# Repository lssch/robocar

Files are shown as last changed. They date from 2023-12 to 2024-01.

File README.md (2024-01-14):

# robocar
This is a third semester project at FHGR to develop a semi autonomous rc car with simple obstacle avoidance. The project consists of three main software components:

- [**STM32 Firmware**](https://github.com/lssch/STM32_Robocar_FW)
- [**ESP32 Firmware**](https://github.com/lssch/ESP32_Robocar_FW)
- [**GUI**](https://github.com/lssch/GUI_robocar)

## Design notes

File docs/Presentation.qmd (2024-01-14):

---
title: "Robocar"
subtitle: "Mobiles Robotikprojekt I"
author: "Lars Schwarz"
date: last-modified
lang: de

title-block-banner: blue
format:
  revealjs: 
    scrollable: true
    multiplex: true
    transition: slide
    transition-speed: fast
    html-math-method: mathjax
    slide-number: true
    show-slide-number: all
    progress: false
    history: true
    chalkboard: true
    preview-links: auto
---

# Übersicht
:::: {.columns}

::: {.column}
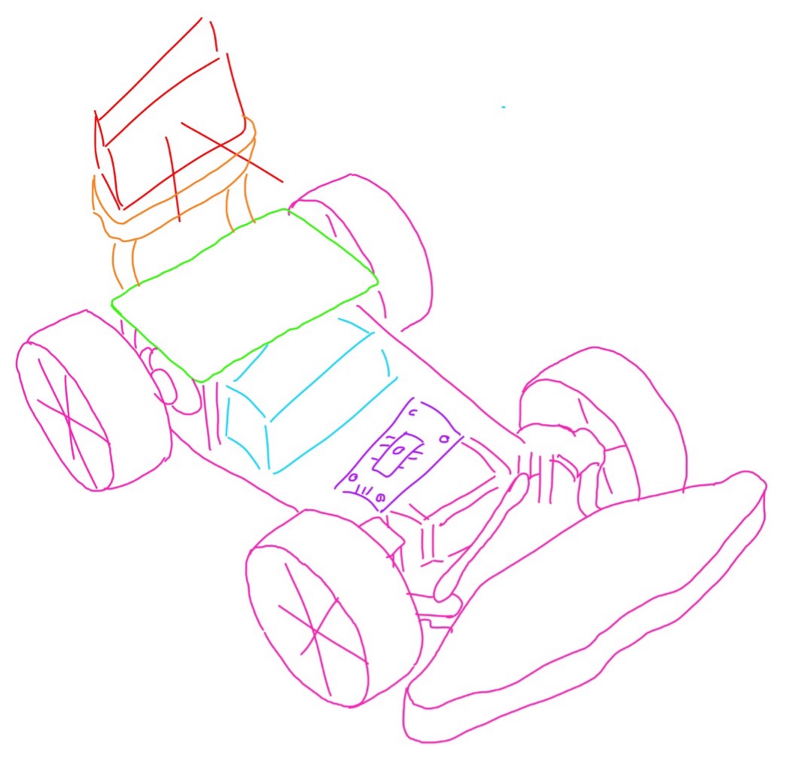
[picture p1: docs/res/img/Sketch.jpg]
Sketch

:::
::: {.column}
::: {.incremental}
- Ferngesteuertes RC-Auto
- Teil-/Vollautonom 
:::
:::

::::

# Mechanik
:::: {.columns}

::: {.column}
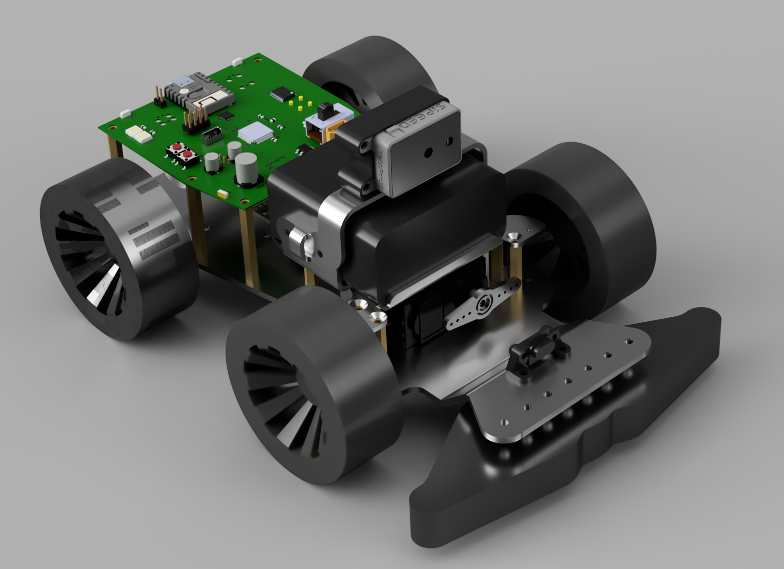
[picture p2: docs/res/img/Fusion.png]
Fusion-Export

:::

::: {.column}
::: {.incremental}
- Neue Grundplatte
- Batteriehalter
- ToF-Kamerahalter
- ToF-Spot-Halter
- Beleuchtungsring VFS
:::
:::
::::

# Elektronik
:::: {.columns}

::: {.column}
::: {.panel-tabset group="language"}

## Vorderseite
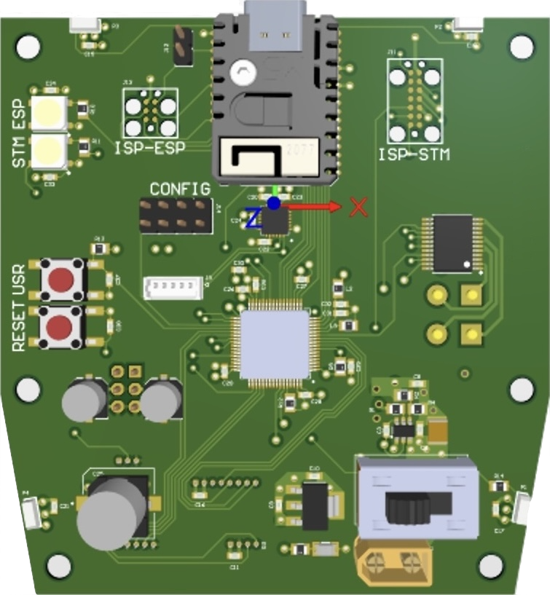
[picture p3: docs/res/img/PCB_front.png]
Vorderseite


## Rückseite
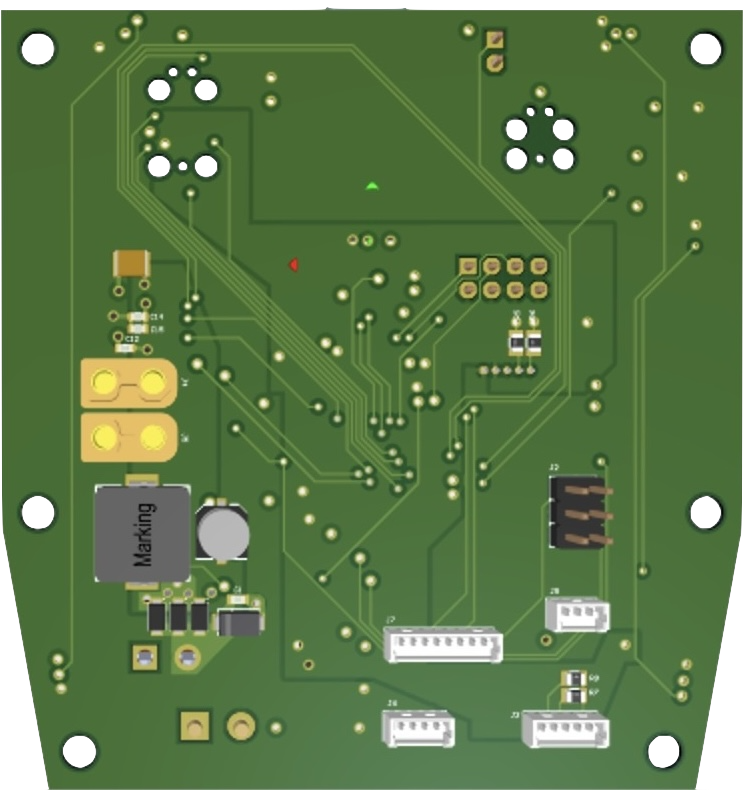
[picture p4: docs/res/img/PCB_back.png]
Rückseite


:::
:::

::: {.column}
::: {.incremental}
- Platzsparend
- Keine Steckmodule
:::

::: {.fragment}
**Fehler**

- RX/TX für debugging vertauscht
:::

::: {.fragment}
**Siliziumhimmel**

- 1 Mikrocontroller
- 4 H-Brücken
:::

:::

::::

# Software
Comments

## Softwareaufbau
::: {.incremental}
- 3 Verschiedene Oberflächen
  - **Firmware**: STM32 in C++
  - **Firmware**: ESP32 in C++
  - **GUI**: Robocar Visualisierung in [Typescript](https://www.typescriptlang.org/)
- Eigene Softwaremodule für jede Hardwarekomponente
  
  :::: {.columns}
  ::: {.column}
    - IMU
    - ToF-Kamera
    - Visual-Flow-Sensor
  :::
  ::: {.column}
    - Neopixel
    - Servo
    - H-Brücke
  :::
  ::::
:::

## Kommunikation mit GUI
```{mermaid}
sequenceDiagram
    participant STM32
    participant ESP32
    participant Laptop

    Note over ESP32,STM32: SPI fullduplex

    loop Sync
      ESP32 -> STM32: package TX/RX
    end

    loop Sample
      ESP32 ->> Laptop: EUI read package
    end

    Laptop ->> ESP32: EUI write package

    Note over ESP32,Laptop: UART
```

## Regelung
$$x_{\text{a}}(t) = K_{\text{p}} \cdot x_{\text{e}}(t) + K_{\text{i}} \cdot \int x_{\text{e}}(t) \, \mathrm{d} t + K_{\text{d}} \cdot \dot x_{\text{e}}(t) $$

::: {.fragment}
:::: {.columns}
::: {.column}
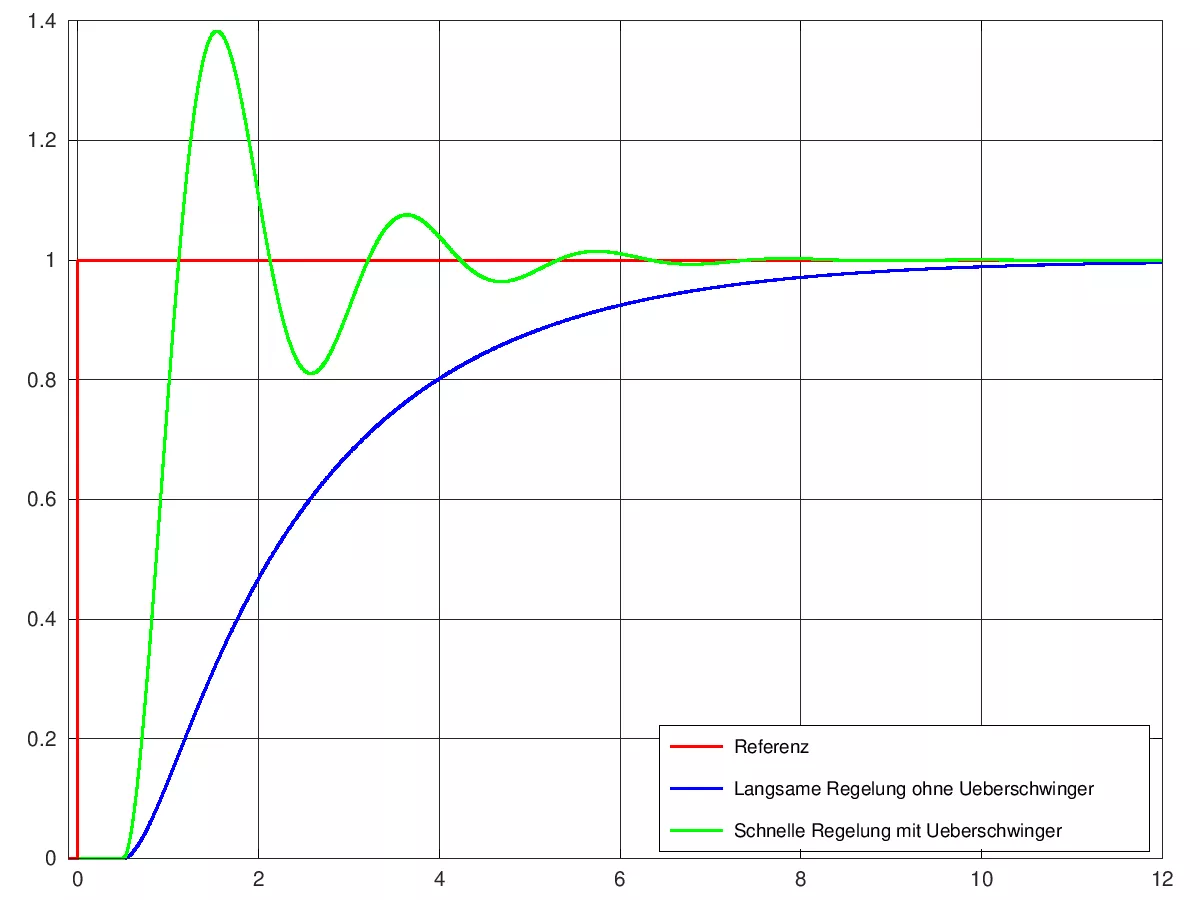
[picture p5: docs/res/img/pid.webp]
Sprungantwort

:::

::: {.column}
::: {.incremental}
- Geschwindigkeit
- Abstand zu Objekt
- Tuning von $K_{\text{p}}, K_{\text{i}}, K_{\text{d}}$
:::
:::
:::
::::

## Falsches Tuning

{{< video res/data/PID.mov >}}

## Codestats {auto-animate=true}
```{mermaid}
%%{init: {"pie": {"textPosition": 0.5}} }%%
   pie
    title Eigene Codezeilen
    "STM32 ca. 2'500" : 2500
    "ESP32 ca. 900" : 900
    "GUI ca. 3'300" : 3300
```

## Codestats {auto-animate=true}
```{mermaid}
%%{init: {"pie": {"textPosition": 0.5}} }%%
pie title Anzahl Codezeilen
    "Eigene STM32 ca. 2'500" : 2500
    "Eigene ESP32 ca. 900" : 900
    "Eigene GUI ca. 3'300" : 3300
    "STM32 ca. 33'500" : 33500
    "ESP32 ca. 16'100" : 16100
    "GUI ca. 236'700" : 236700
```

# Demonstration

# Fragen

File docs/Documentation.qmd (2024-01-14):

---
title: "Dokumentation Robocar"
subtitle: "Mobiles Robotikprojekt I"
author: "Lars Schwarz"
date: last-modified

title-block-banner: blue

toc: true
number-sections: false
highlight-style: pygments

format:
  html:
    code-fold: true
    code-tools:
      source: false
      toggle: true
    code-line-numbers: true
    code-overflow: scroll
    html-math-method: mathjax
  pdf:
    pdf-engine: pdflatex
    latex-auto-install: true
    documentclass: article
    papersize: a4
    geometry:
      - left=2cm
      - right=2cm
      - top=2cm
      - bottom=2cm
    lof: true
    header-includes:
      - \usepackage{bbold}
      - \usepackage{float}
      - \floatplacement{figure}{H}
      - \newcommand{\N}{\mathbb{N}}
      - \newcommand{\Z}{\mathbb{Z}}
      - \newcommand{\Q}{\mathbb{Q}}
      - \newcommand{\R}{\mathbb{R}}
      - \newcommand{\C}{\mathbb{C}}
      - \newcommand{\D}{\mathbb{D}}
      - \newcommand{\W}{\mathbb{W}}
      - \newcommand{\M}{\mathbb{M}}
      - \newcommand{\K}{\mathbb{K}}
      - \newcommand{\e}{\mathrm{e}}
      - \renewcommand{\i}{\mathrm{i}}
      - \renewcommand{\j}{\mathrm{j}}
      - \newcommand{\dd}{\,\mathrm{d}}
      - \newcommand{\pp}{\partial}
      - \newcommand{\NA}{\text{N/A}}
      - \newcommand{\ul}[1]{\underline{#1}}
      - \newcommand{\uul}[1]{\underline{\underline{#1}}}
      - \renewcommand{\vec}[1]{\boldsymbol{\mathrm{#1}}}
      - \newcommand{\uvec}[1]{\boldsymbol{\hat{\mathrm{#1}}}}
      - \newcommand{\abs}[1]{\left\vert#1\right\vert}
      - \newcommand{\vabs}[1]{\left\vert\left\vert#1\right\vert\right\vert}
      - \renewcommand{\angle}[1]{\left\langle#1\right\rangle}
      - \newcommand{\ceil}[1]{\left\lceil#1\right\rceil}
      - \newcommand{\floor}[1]{\left\lfloor#1\right\rfloor}
      - \newcommand{\sgn}[1]{\operatorname{sgn}\left(#1\right)}
      - \renewcommand{\Re}[1]{\operatorname{Re}\left(#1\right)}
      - \renewcommand{\Im}[1]{\operatorname{Im}\left(#1\right)}
      - \newcommand{\cis}[1]{\operatorname{cis}\left(#1\right)}
      - \renewcommand{\arg}[1]{\operatorname{arg}\left(#1\right)}
      - \renewcommand{\div}[1]{\operatorname{div}\left(#1\right)}
      - \newcommand{\rot}[1]{\operatorname{rot}\left(#1\right)}
      - \newcommand{\tr}[1]{\operatorname{tr}\left(#1\right)}
      - \renewcommand{\det}[1]{\operatorname{det}\left(#1\right)}
      - \newcommand{\spec}[1]{\operatorname{Spec}\left(#1\right)}
      - \renewcommand{\dim}[1]{\operatorname{dim}\left(#1\right)}
      - \newcommand{\img}[1]{\operatorname{img}\left(#1\right)}
      - \renewcommand{\ker}[1]{\operatorname{ker}\left(#1\right)}
---

{{< pagebreak >}}

# Einführung
Diese Dokumentation dient zur Bedienung und Weiterentwicklung des "Robocars", das im Rahmen des [Mobile Robotics Projekt 1](https://www.fhgr.ch/fileadmin/studium/bachelorangebot/mobile_robotics/FHGR-Bachelorstudium-Mobile_Robotics-Moduluebersicht.pdf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) an der [FHGR](https://fhgr.ch) während des dritten Semesters entwickelt wurde.

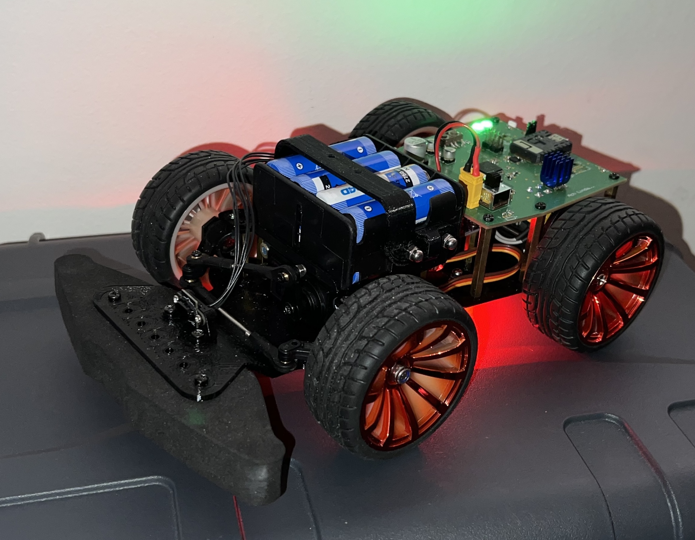
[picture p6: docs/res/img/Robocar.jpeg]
Robocar


Sämtliche Files sind in folgemdem [GitHub-Repo](https://github.com/lssch/robocar) zu finden.

::: {.callout-note title="Info"}
- Diese Dokumentation soll als Zusatz dienen und nicht als Ersatz für die Sourcecode Dokumentation.
- Dieses Dokument wurde mit [Quarto-Markdown](https://quarto.org) erstellt und ist sowohl in PDF (ohne Videos) als auch in HTML (bevorzugt) verfügbar.
:::

# Übersicht
Das Robocar basiert auf einem stark modifiziertem Chassis von [YF-Robot](https://yfrobot.com/collections/robot-kits/products/steering-gear-robot) und verwendet einen [STM-32F446RE](https://www.st.com/en/microcontrollers-microprocessors/stm32f446re.html) Mikrocontroller, welcher auf einem eigens dafür entworfenem PCB mit verschiedenen Peripherien ([M5Stack ESP32-S3](https://docs.m5stack.com/en/core/StampS3), [IMU](https://invensense.tdk.com/products/motion-tracking/6-axis/mpu-6050/), [ToF-Kamera](https://wiki.sipeed.com/hardware/en/maixsense/index.html), [ToF-Sensor](), [Visual-Flow-Kamera](https://www.mouser.ch/ProductDetail/Broadcom-Avago/ADNS-3080?qs=RuhU64sK2%252Bsop/60ZpFX6g%3D%3D)) kommuniziert.

Das Robocar soll mittels sehr günstiger Hardware ferngesteuert werden und als weiterführende Ziele gewisse Assistenzfunktionen wie Kollisionsdetektion und Spurhalteasistenz verfügen. Weiter soll eine einfache Kollisionsverhinderung mittels Ausweichmanöver implementiert sein.

{{< pagebreak >}}

# Handbuch
## Benötigte Komponenten
- Robocar
- Geladene Batterien!
- Laptop mit GUI-Applikation

::: {.callout-tip title="Tip"}
  Sicherstellen, dass die Batterien ganz geladen sind.
:::

## Hardware

1. Geladene Batterien in den Batteriehalter einsetzen.
2. Batteriehalter in die vorgesehene Halterung einsetzen.
3. Batteriestecker XT30 mit dem PCB verbinden.
4. Robocar am Hauptschalter einschalten.

::: {.callout-important title="Vorsicht"}
  <p>
    Beim Einsetzen der Batteriehalterung in die vorgesehene Position auf dem Robocar, muss darauf geachtet werden, dass die Litzen des ToF-Spot Sensors nicht gequetscht werden!
  </p>
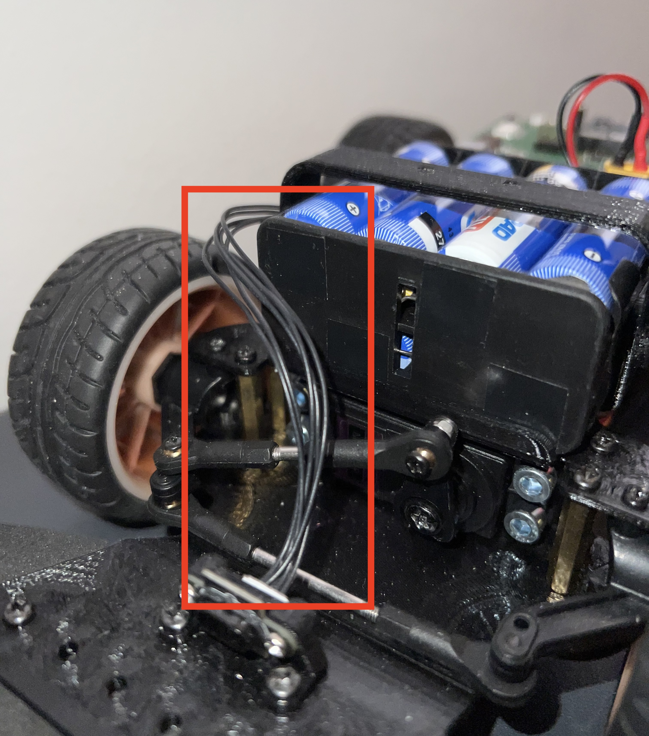
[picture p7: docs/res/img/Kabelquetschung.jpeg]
Kabelquetschung
  
:::

## GUI 
Über die GUI können alle Sensordaten live abgefragt werden und alle Parameter persistent verändert werden.

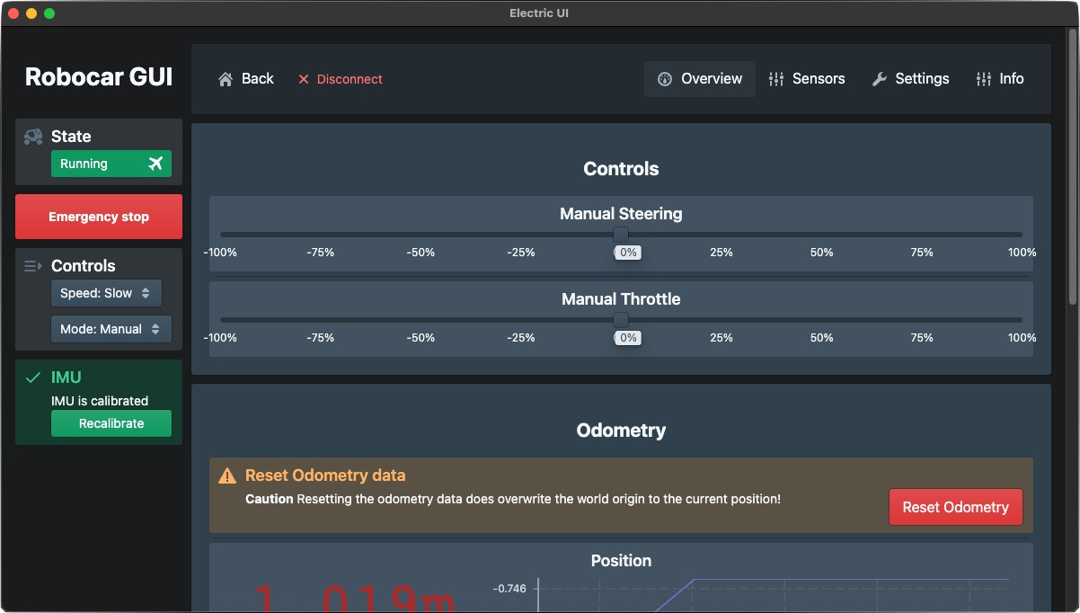
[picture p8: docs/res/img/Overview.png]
GUI Robocar


1. GUI-Applikation starten

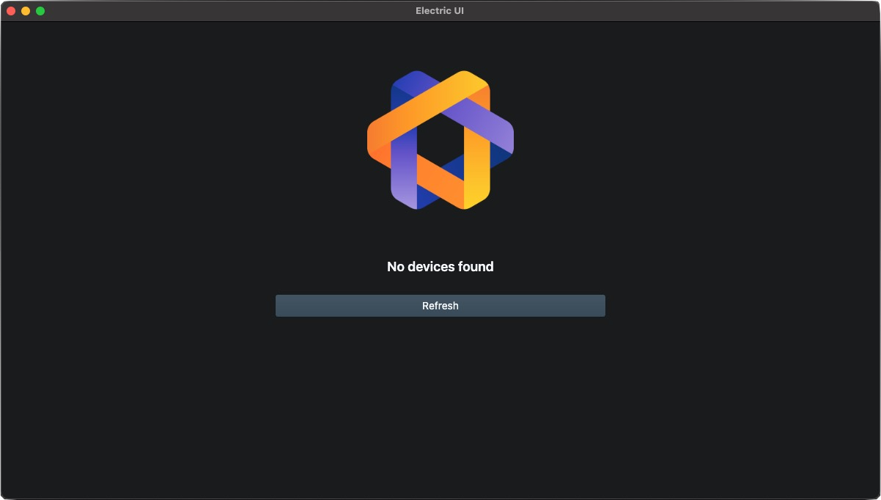
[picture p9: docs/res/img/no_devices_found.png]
GUI Robocar keine Geräte
  

1. Verbindung mit dem Robocar über WIFI/Bluetooth oder Serial (kabelgebunden) herstellen.

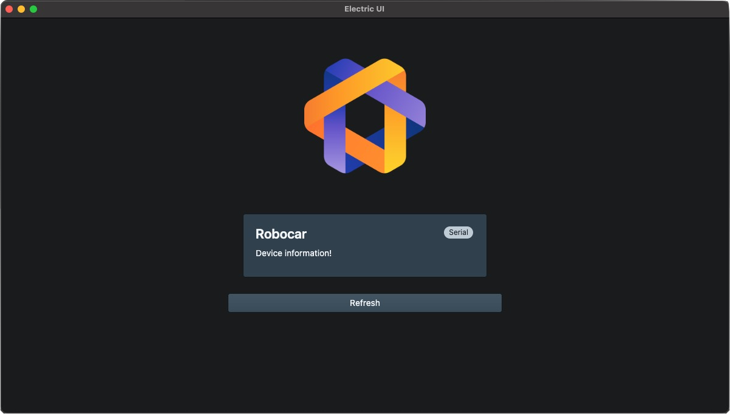
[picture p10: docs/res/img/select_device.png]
GUI Robocar verbinden mit Endgerät
  

1. Werte und Parameter abfragen

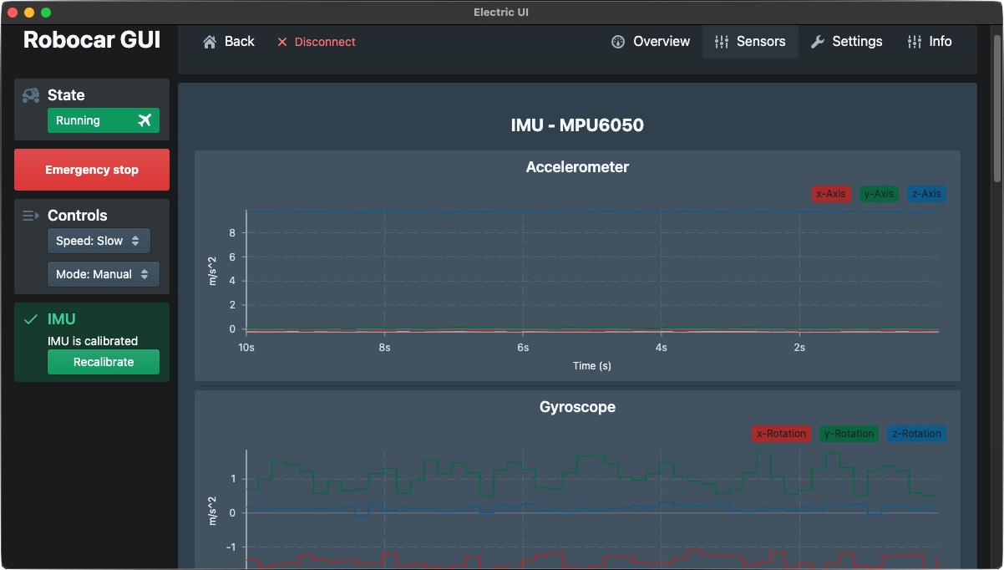
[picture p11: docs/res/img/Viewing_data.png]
GUI Robocar Datenseite
  

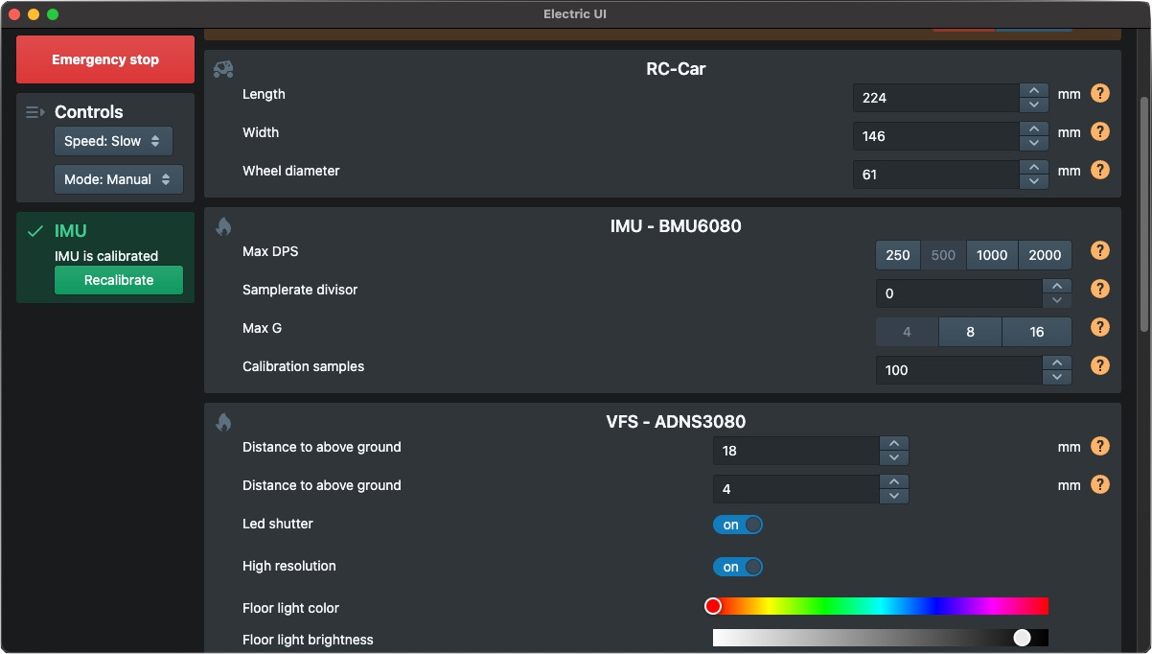
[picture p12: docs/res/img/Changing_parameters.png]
GUI Robocar Parameterseite
  

## Spass haben
Folgende Betriebsmodis wurden implementiert:

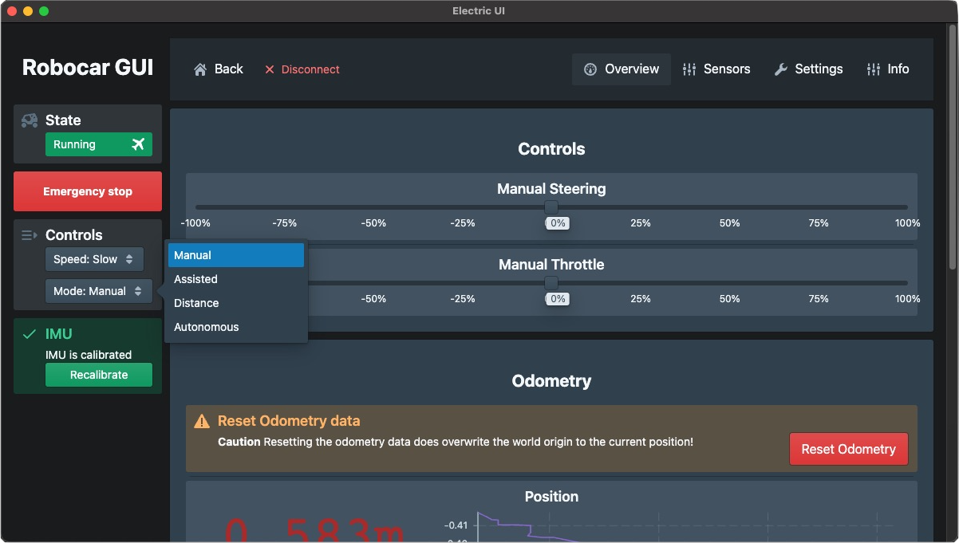
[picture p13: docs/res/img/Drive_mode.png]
Betriebsmodis


- **Manuelles Verfahren**: Das Robocar kann mittels Slider in der GUI oder dem Controller bewegt werden.
- **Assistiertes Verfahren**: Das Robocar kann mittel Slider in der GUI oder dem Controller, unter Berücksichtigung der Spurhaltefunktion, bewegt werden.
- **Distanz-Modus**: Das Robocar fährt auf ein Objekt zu und hält bei einer parametrisierten Distanz mit einstellbarer Tolleranz vor dem Objekt automatisch an.
- **Kollisionsverhinderung**: Das Robocar umfährt selbstständig Hindernisse ohne Eingreifen einer Drittperson.

# Hardware
Im CAD wurde das gesammte Auto nachgezeichnet und anschliessend so abgeändert.

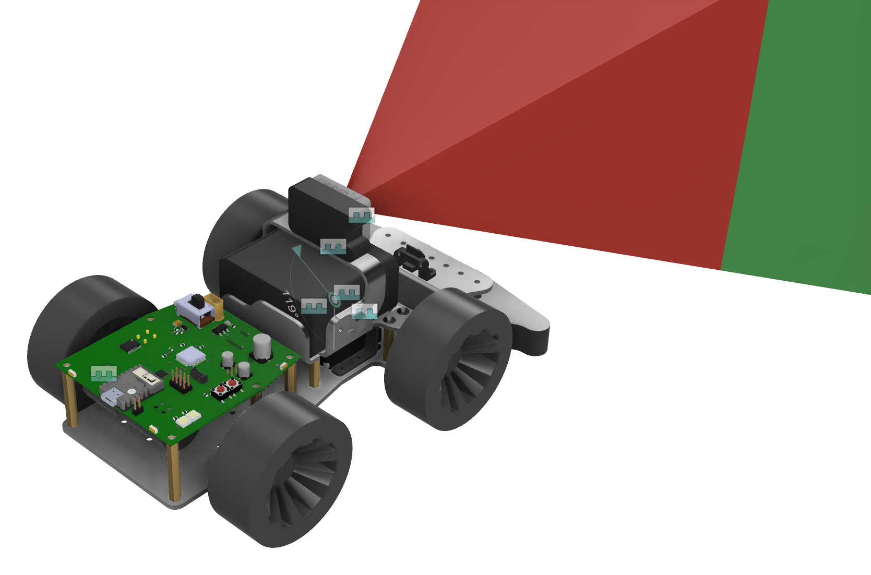
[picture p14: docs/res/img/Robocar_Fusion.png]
Fusion-Export


Für das Robocar wurden folgende Komponenten entworfen:

- **Grundplatte** 
  
  Bindeglied für alle Komponenten und massgebend für die Steifigkeit des Fahrzeuges. Der Radabstand konnten im Vergleich zum Original-Chassis deutlich verringert werden.
  {{< video res/data/Groundplate.mp4 >}}

- **Batteriehalter** 

  Der Batteriehalter wurde über der Vorderachse angebracht, um den Schwerpunkt nach vorne zu bringen. Die Batteriehalterung dient zudem als Halter für die Kamera.
  {{< video res/data/Batteriehalter.mp4 >}}

- **VFS mit Beleuchtungsring**

  Mechanisch stellte der Visual-Flow-Senser die grösste Herausforderung dar. Es musste darauf geschaut werden, dass der Sensor ein scharfes Bild des Boden aufnimmt und zudem musste der Boden noch zusätzlich beleuchtet werden. 
  
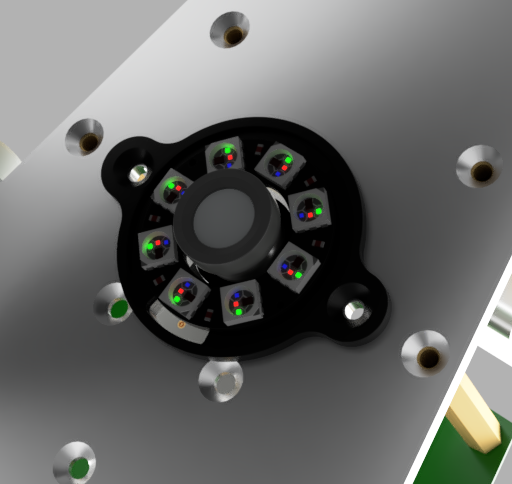
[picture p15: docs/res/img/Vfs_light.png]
VFS-Beleuchtung
  

- **ToF-Spot Halterung**
  
  Der ToF-Spot Sensor wurde so auf dem Chassis montiert, dass er möglichst nahe über den Boden hinweg schaut, um so auch niedrige Objekte zu detektieren.

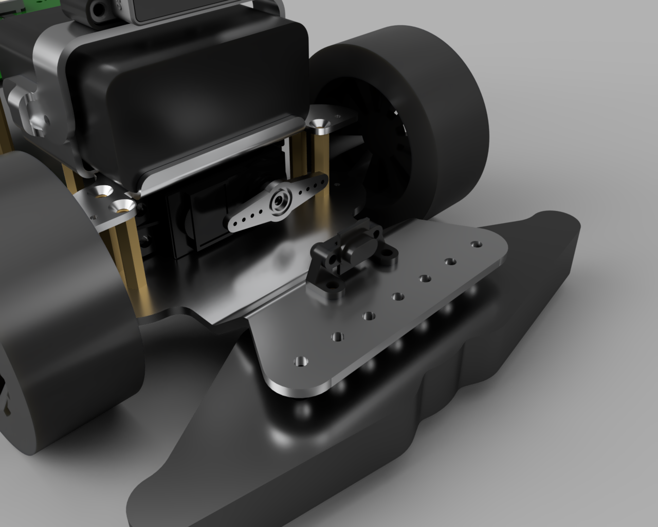
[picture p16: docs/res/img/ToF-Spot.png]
ToF-Spot Halterung
  

# Elektronik
Die Elektronik basiert auf einem eigens entworfenen PCB. Auf dem PCB wird die gesamte Spannungsregelung sowie Spannungverteilung an die jeweiligen Peripherien geregelt sowie die Kommunikation mit dem Mikrocontroller realisiert.

::: {#fig-pcb layout-ncol=2}
Vorderseite

Rückseite

PCB
:::

Das Robocar wird durch 8xAA Batterien versorgt und verfügt über ein zweistufiges Spannungswandlersystem, um Spannungslevels für $12\,\text{VDC}$ (Endstufe Motorensteuerung), $5\,\text{VDC}$ (Peripherie) und  $3.3\,\text{VDC}$ (Mikrocontroller) zu erzeugen. Über einen Schalter kann die Batterie und somit die Versorgungsspannung ($9\,\text{V} - 14\,\text{V}$) vom PCB getrennt werden.

## Blockschaltbild
Blockschaltbild

## Schema & PCB-Design

Das PCB verfügt über die folgenden Komponenten:

- Spannungsversorgung
  - $12\,\text{VDC}$ Eingang mit ESD- und Polaritäts-Schutz
  - $12\,\text{VDC} \Rightarrow 5\,\text{VDC}$ [BUC-Konverter](https://www.wikiwand.com/de/Abw%C3%A4rtswandler)
  - $5\,\text{VDC} \Rightarrow 3.3\,\text{VDC}$ [LDO-Spannungsregler](https://www.wikiwand.com/de/Spannungsregler)
- Mikrocontroller 
  - Maincontroller STM32
  - Kommunikationscontroller ESP32
- Debugging
  - 1 Power-ok LED
  - Reset-Button
  - Konfigurierbarer User-Button
  - 2 RGB Statusled für Mikrocontroller (WS2812)
  - Tag-Connect 6-Pol für ESP32
  - Tag-Connect 14-Pol für STM32
- Peripherie
  - Lagesensor (MPU6050)
  - ToF-Kamera (MaixSense-A0101)
  - ToF-Spot (TF-LC02)
  - Fluss-Sensor (ADNS3080)
  - Motorentreiber (TB6612FNG)
  - Navigationslichter (SK6812)
  - Ringbeleuchtung Fluss-Sensor (8xWS2812)
- Stecker
  - 1 XT30 Stecker für den Batterieanschluss
  - 2 XT30 Buchsen für Motoren
  - 2 3-Pin Header für Servos
  - 4 GPIO Pins mit $\text{GND}$

Dem Schema sind alle weiteren Details bezüglich Auslegung und Dimensionierung zu entnehmen.

::: {#fig-Schema layout-ncol=2}
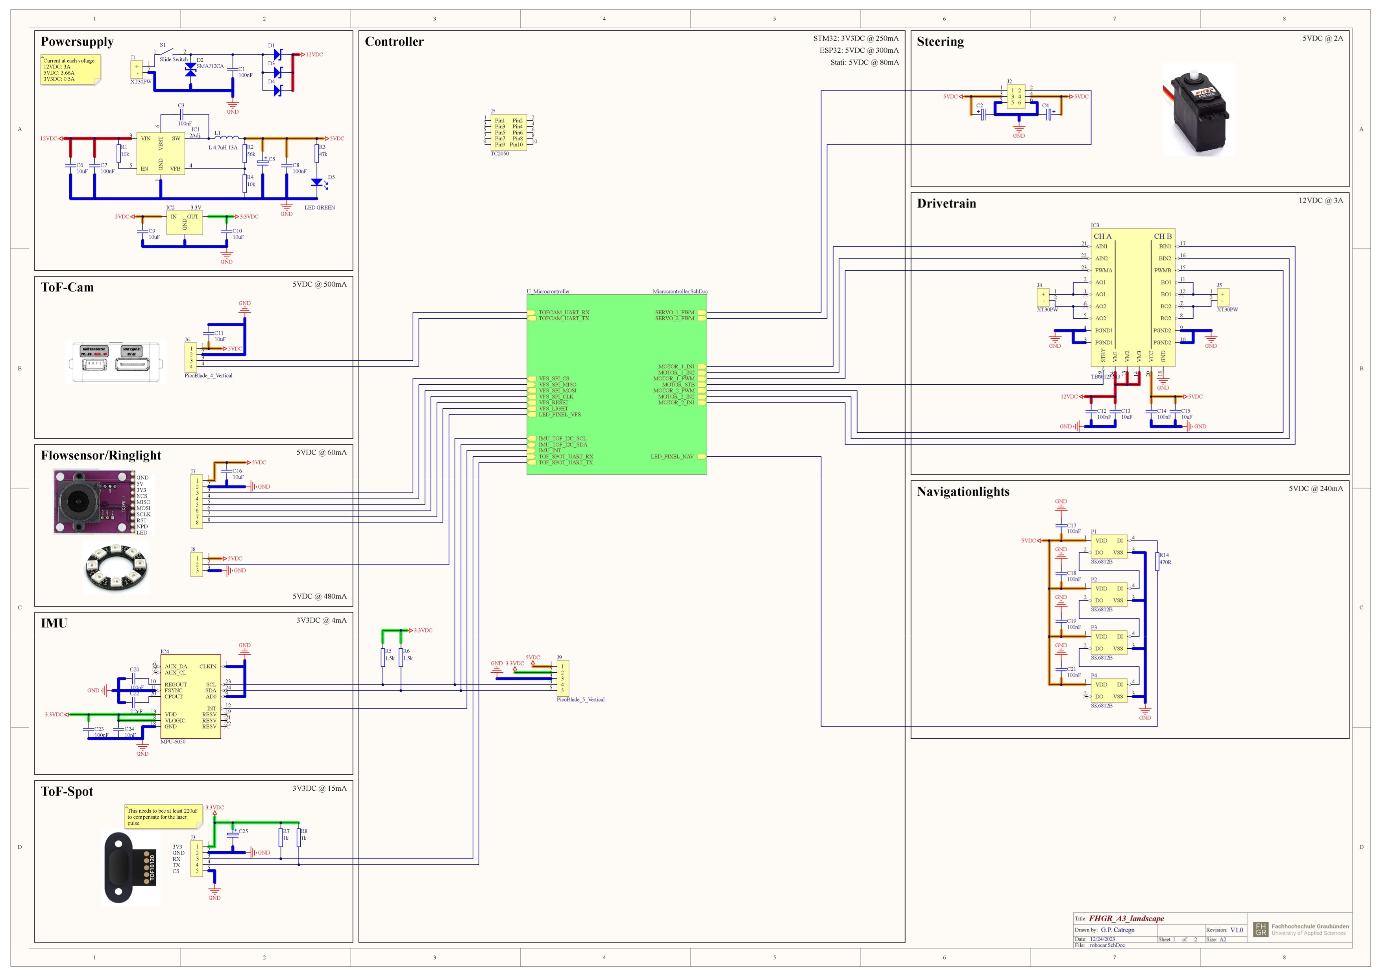
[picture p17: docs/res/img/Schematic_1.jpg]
Mikrocontroller


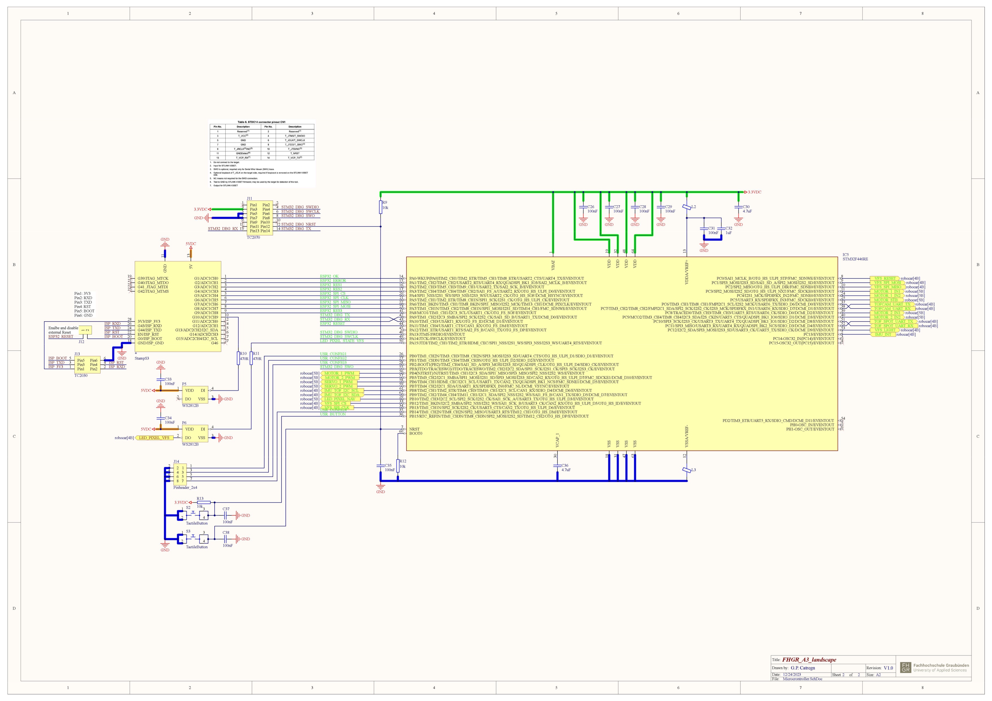
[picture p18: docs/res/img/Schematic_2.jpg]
Peripherie


Schema
:::

::: {.callout-note title="Info"}
Für Komponenten, die nicht der FHGR-Altium Bibliothek entnommen werden konnte, wurde jeweils eine eigene Bibliothek erstellt. Diese ist unter `PCB/lib` zu finden.
:::

## Messungen BUC-Konverter
### Wirkungsgrad
Der Wirkungsgrad des BUC-Konverter wurde mithilfe eines Messwiderstandes von $R = 10\,\Omega$ gemessen, was zu einem theoretischen Strom von $I = 500\,\text{mA}$ auf der Abgangsseite führt.

**Messungen**

|  | Spannung | Strom |
|:-----|:-----|:-----|
| **Eingangseite** | $U_{in} \approx 12.24 \,\text{V}$ | $I_{in} \approx 290 \,\text{mA}$ |
| **Ausgangseite** | $U_{out} \approx 4.89 \,\text{V}$ | $I_{out} \approx 510 \,\text{mA}$ |

**Berechnung**
$$\eta = \frac{P_{out}}{P_{in}} = \frac{U_{out} \cdot I_{out}}{U_{in} \cdot I_{in}} \approx 72\,\%$$

```{python}
#| code-summary: "Nummerische Implementation"
U_in = 12.24
I_in = 0.29
U_out = 4.98
I_out = 0.51

print(f'P_in = {(P_in := U_in*I_in):.2f} W')
print(f'P_out = {(P_out := U_out*I_out):.2f} W')
print(f'n = {P_out/P_in*100:.2f} %')
```
::: {.callout-note title="Note"}
Bei der Messung wurden die folgenden Komponenten nicht entfernt, da diese aufwendig herausgelötet werden müssten:

- Mikrocontroller STM32
- Kommunikationscontroller ESP32
- IMU MPU6050

Aus diesem Grund fliesst immer ein gewisser Strom, der bei der Abgangsseite nicht erfasst werden kann. Dies führt zu einem Querstrom, welcher nicht erfasst werden kann und eine genaue Messung verunmöglicht sowie den tiefen Wirkungsgrad ausmacht.
:::

### Spannungsrippel
::: {#fig-ripple layout-ncol=2}
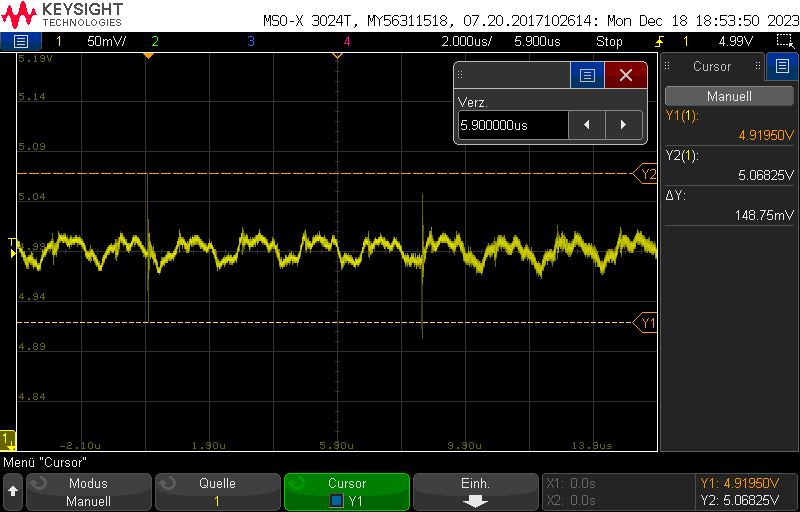
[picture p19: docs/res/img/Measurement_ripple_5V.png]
KO


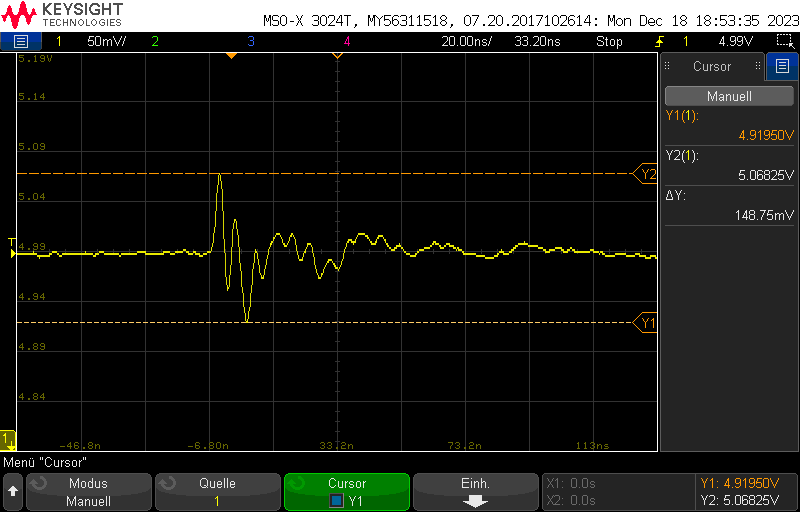
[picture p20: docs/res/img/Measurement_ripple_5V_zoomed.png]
KO Ausschnitt


Spannungsrippel
:::

Der Spannungsrippel beträgt ca. $\Delta U_5 \approx 150\,\text{mVDC}$, was $3\,\%$ von $5\,\text{VDC}$ entspricht.

::: {.callout-note title="Note"}
Ein Grossteil der Spannungsrippel macht hierbei das ESP32 aus. Wird dieses ausgelötet und die Messung wiederholt, so sind um einiges bessere Werte zu erwarten.
:::

# Software
## Softwareaufbau
Das Robocar wurde aufgrund der erhöten Übersichtlichkeit und Abkapselung der einzelnen Module mit [C++](https://www.wikiwand.com/de/C%2B%2B) programmiert. Dafür wurde für jede Komponente ein eigenes Modul entwickelt und implementiert.

| Komponente | Modulname | Softwaremodul |
|:---|:---|:---:|
| [IMU](https://invensense.tdk.com/products/motion-tracking/6-axis/mpu-6050/) | MPU60X0 | [Github](https://github.com/lssch/STM32_Robocar_FW/tree/main/Core/Inc/mpu60X0) |
| [ToF-Kamera](https://wiki.sipeed.com/hardware/en/maixsense/index.html) | A010 | [Github](https://github.com/lssch/STM32_Robocar_FW/tree/main/Core/Inc/A010) |
| ToF-Sensor | TFLC02 | [Github](https://github.com/lssch/TFLC02) |
| [Visual-Flow-Kamera](https://www.mouser.ch/ProductDetail/Broadcom-Avago/ADNS-3080?qs=RuhU64sK2%252Bsop/60ZpFX6g%3D%3D) | ADNS3080 | [Github](https://github.com/lssch/ADNS3080) |
| [Neopixel](https://learn.adafruit.com/adafruit-neopixel-uberguide/the-magic-of-neopixels) | WS2812/SK6812 | [Github](https://github.com/lssch/NeoPixel) |
| Servo | MG90| [Github](https://github.com/lssch/Servo) |
| [H-Brücke](https://toshiba.semicon-storage.com/info/TB6612FNG_datasheet_en_20141001.pdf?did=10660&prodName=TB6612FNG) | TB6612FNG | [Github](https://github.com/lssch/TB6612FNG) |

## Flussdiagramm
```{mermaid}
stateDiagram
  state "Robocar Statemachine" as ROBOCAR {
    state "Initialising" as INIT
    state "Running - Substatemachine Operatingmode" as RUNNING {
      state "Manual driving" as MANUAL
      state "Assisted driving" as ASSISTED
      state "Driving to disatance" as DISTANCE
      state "Autonomous driving" as AUTONOMOUS

      [*] --> MANUAL

      MANUAL --> ASSISTED
      MANUAL --> DISTANCE
      MANUAL --> AUTONOMOUS

      ASSISTED --> MANUAL
      ASSISTED --> DISTANCE
      ASSISTED --> AUTONOMOUS

      DISTANCE --> MANUAL
      DISTANCE --> ASSISTED
      DISTANCE --> AUTONOMOUS

      AUTONOMOUS --> MANUAL
      AUTONOMOUS --> ASSISTED
      AUTONOMOUS --> DISTANCE
    }

    note right of RUNNING
      Substatemachine to handle the 
      requestet driving mode by the GUI.
    end note

    state "Emergency Stop" as EMS

    [*] --> INIT
    INIT --> EMS : Emergencystop
    INIT --> RUNNING : Initialisation done

    RUNNING --> EMS : Emergencystop

    EMS --> INIT : Quit

  note left of RUNNING
    Main statemachine of the Robocar.
  end note
  }
```

## Funktionalität
Die Hauptschwierigkeit bei der Implementierung ist die Synchronisation der [Datenstrukturen](https://github.com/lssch/types) zwischen den beiden Mikrocontrollern. So müssen Überschreibungen vermieden werden und requests/acknowlidges passend gesetzt und gelöscht werden. Zwischen dem ESP32 und dem STM32 wurde eine SPI-Kommunikation eingerichtet und das ESP32 kommuniziert mit dem Laptop über UART. Über ein [eigenes Protokoll](https://github.com/lssch/comms) zwischen STM32 und ESP32 wird in jedem Zyklus, welcher durch das ESP32 initiiert wird die Variablen zwischen den Mikrocontrollern synchronisiert. Dabei wird von simultan aus/in den DMA Speicher auf beiden Mikrocontrollern geschrieben.
```{mermaid}
sequenceDiagram
    participant STM32
    participant ESP32
    participant Laptop

    Note over ESP32,STM32: SPI fullduplex

    loop Sync
      ESP32 -> STM32: package TX/RX
    end

    loop Sample
      ESP32 ->> Laptop: EUI read package
    end

    Laptop ->> ESP32: EUI write package

    Note over ESP32,Laptop: UART
```

::: {.callout-note title="Note"}
Bei einer Hardware-Revision würde es Sinn machen die SPI-Kommunikaiton durch eine UART-Kommunikation zu ersetzen und das ESP32 nur als UART-Bridge einzusetzen.
:::

Der Rest der Software ist trivial und [selbsterklärend](https://www.wikiwand.com/en/Self-documenting_code).

::: {.callout-tip title="Tip"}

Useless comment

- A comment is a failure to express yourself in code. If you fail, then write a comment; but try not to fail. [Robert Martin](https://twitter.com/unclebobmartin/status/870311898545258497)
- The comments will inevitably become out of date, and untrustworthy comments are worse than no comments at all. [The Pragmatic Programmer](https://www.goodreads.com/book/show/4099.The_Pragmatic_Programmer)
- [Make your code explain itself. If it has too many comments, you’re doing it wrong!](https://medium.com/@douglas.iacovelli/make-your-code-explain-itself-if-it-has-too-many-comments-youre-doing-it-wrong-c856a0df6a65)

:::

## Modulbeschreibungen
Die einzelnen Modulbeschreibungen können den jewiligen `.hpp` Source-Dokumenten als [Doxygen](https://www.doxygen.nl) entnommen werden und werden hier nicht explizit aufgeführt!

## ToDo-Software
ToDo's für eizenlne Module den einzelnen Doxygen-Kommentaren zu entnehmen und werden hier nicht explizit gelistet. 

- Generell muss ein [Refactoring](https://www.wikiwand.com/de/Refactoring) getätigt werden.
- Implementierung eines [Watchdog](https://www.wikiwand.com/de/Watchdog).
- Implementierung des Kollisionsverhinderungs-Modus
- Umschalten auf die Odometry-Daten des IMU wenn die Bodequalität des VFS zu schlecht wird.
- "Richtige" Implementation eines PI-Speedcontrollers -> Jetztiger oszilliert praktisch ungedämpft.

# Stand der Dinge

## Fernsteuerung
Das Robocar ist zur Zeit nicht in der Lage drahtlos ferngesteuert zu werden. Dies kann jedoch mit geringem Aufwand implementiert werden, sobald das nächste Update von [Electricui](https://electricui.com/) puliziert wird. (Anfangs des Projektes wurde bei den Entwicklern nachgefragt und ein Release sollte bis Ende Dezember 2023 sichergestellt sein.)

## Implementation X-Box-Kontroller
Das Robocar ist zur Zeit nicht in der Lage über einen X-Box-Kontroller ferngestuert zu werden. Dies kann jedoch mit geringem Aufwand implementiert werden, sobald das nächste Update von [Electricui](https://electricui.com/) puliziert wird. (Anfangs des Projektes wurde bei den Entwicklern nachgefragt und ein Release sollte bis Ende Dezember 2023 sichergestellt sein.)

## Kommunkation zwischen den Mikrocontrollern
Die Kommunikaiton zwischen den Mikrocontrollern ist hochgradig ineffizient und könnte um einiges datensparender implementiert werden. Dadurch würden sich auch die Zugriffszeiten von der GUI zum ESP32 verringern, was eine höhere Aktualisierungsrate ermöglicht.

Zur Zeit werden immer alle Bytes der gesamten Datenstruktur übertragen, auch wenn nur ein Teil der Datenstruktur angefragt wurde. Ein Grossteil davon macht das Kamerabild der ToF-Kamera aus, was bis zu 10'000 Bytes betragen kann.

## ToF-Kamera
Leider gelang es nicht, die Pixeldaten der Kamera auf den STM32 zu übertragen. Die UART-Schnittstelle scheint auf zwei verschiedenen Kameras immer deaktiviert zu sein. Auch wenn diese über das Konfigurationstool aktiviert wird. Aus diesem Grund wurde der Kollisionsverhinderungs-Modus auch nicht implementiert. 

## Visualisierung
Die Visualisierung wurde nicht kompiliert, um ohne Entwicklungsumgebung zu funktioniern. Dies kann jedoch nachträglich für alle gänigen Plattformen (Windows, MacOS, Linux) gemacht werden.

## Parameterhandler
Zur Zeit können keine Parameter persisteng gespeichert werden. Bei einem Neustart gehen alle Werte verlohren. Für den STM32F401RE funktioniert der Code und ein Registermap des Flash-Speichers ist im Web zu finden. Für den STM32F446RE ist keine Dokumentation über Den Flashaufbau zu finden und die Pages und Addressen stimmen nicht mit denen des STM32F401RE überein.

# Bekannte Probleme
## Reset des Robocars
Wird über den Reset-Button ein Reset-Event ausgelöst, so ist es möglich, dass das IMU über den I2C Bus nicht gefunden wird und die Software nach einer parametrisierten Anzahl an Pingversuchen automatisch den Error-Handler aufruft.

```cpp
  if (imu.init(3) != SUCCESS) Error_Handler();
```

## Verbindungsprobleme mit GUI
Zum Teil wird das Robocar von der GUI nicht erkannt und kann somit nicht ferngesteurt werden. In diesem Fall muss nach folgendem Ablauf vorgegangen werden:

1. Robocar vom Laptop trennen
2. Robocar ausschalten
3. GUI "refresh" drücken
4. Robocar erneut mit dem Laptop verbinden
5. Wird das Robocar erkannt, so muss auf dem Robocar der Reset-Button gedrückt werden
6. GUI "connect" drücken

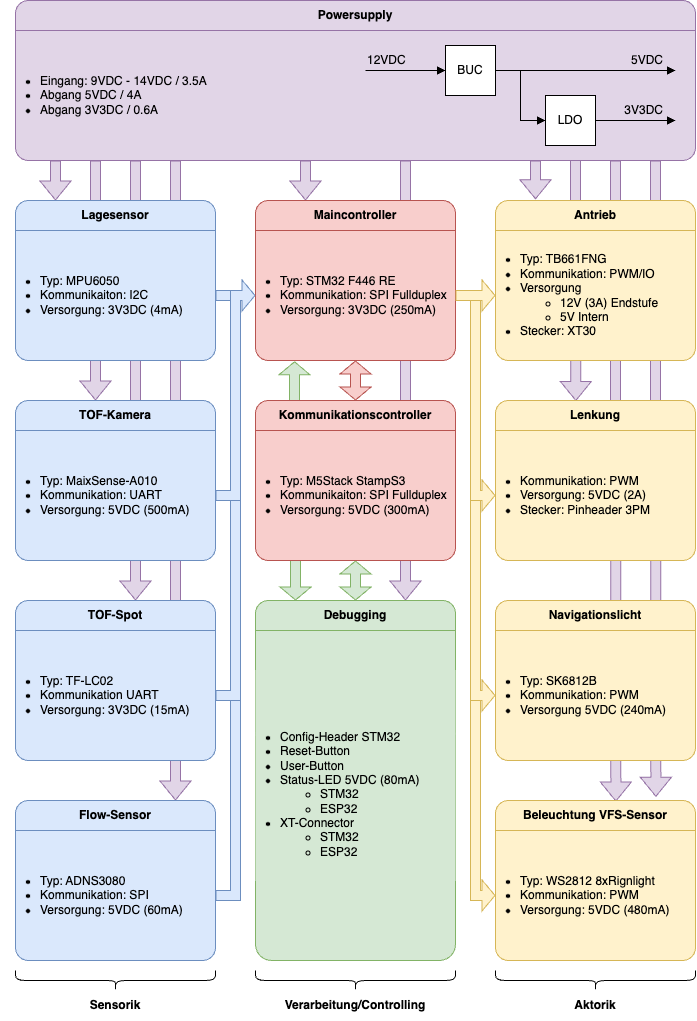
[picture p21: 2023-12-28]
docs/res/img/Blockschaltbild.png

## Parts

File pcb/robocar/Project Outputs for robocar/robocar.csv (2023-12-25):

Line # | Comment | Description | Designator | Quantity | Manufacturer 1 | Manufacturer Part Number 1 | Manufacturer Lifecycle 1 | Supplier 1 | Supplier Part Number 1 | Supplier Unit Price 1 | Supplier Subtotal 1
 | StampS3 |  |  | 1
 | C 100nF 0603 |  | C1 | 1 |  |  |  | Digi-Key | 1276-1012-1-ND
 | C 47uF ALUM |  | C2 | 1 |  |  |  | Digi-Key | PCE4190TR-ND
 | C 100nF 0603 |  | C3 | 1 |  |  |  | Digi-Key | 1276-1012-1-ND
 | C 47uF ALUM |  | C4 | 1 |  |  |  | Digi-Key | PCE4190TR-ND
 | C 47uF ALUM |  | C5 | 1 |  |  |  | Digi-Key | PCE4190TR-ND
 | C 10uF 1210 |  | C6 | 1 |  |  |  | Digi-Key | 445-7004-1-ND
 | C 100nF 0603 |  | C7 | 1 |  |  |  | Digi-Key | 1276-1012-1-ND
 | C 100nF 0603 |  | C8 | 1 |  |  |  | Digi-Key | 1276-1012-1-ND
 | C 10uF 0603 |  | C9 | 1 |  |  |  | Digi-Key | 490-12317-1-ND
 | C 10uF 0603 |  | C10 | 1 |  |  |  | Digi-Key | 490-12317-1-ND
 | C 10uF 0603 |  | C11 | 1 |  |  |  | Digi-Key | 490-12317-1-ND
 | C 100nF 0603 |  | C12 | 1 |  |  |  | Digi-Key | 1276-1012-1-ND
 | C 10uF 1210 |  | C13 | 1 |  |  |  | Digi-Key | 445-7004-1-ND
 | C 100nF 0603 |  | C14 | 1 |  |  |  | Digi-Key | 1276-1012-1-ND
 | C 10uF 0603 |  | C15 | 1 |  |  |  | Digi-Key | 490-12317-1-ND
 | C 10uF 0603 |  | C16 | 1 |  |  |  | Digi-Key | 490-12317-1-ND
 | C 100nF 0603 |  | C17 | 1 |  |  |  | Digi-Key | 1276-1012-1-ND
 | C 100nF 0603 |  | C18 | 1 |  |  |  | Digi-Key | 1276-1012-1-ND
 | C 100nF 0603 |  | C19 | 1 |  |  |  | Digi-Key | 1276-1012-1-ND
 | C 100nF 0603 |  | C20 | 1 |  |  |  | Digi-Key | 1276-1012-1-ND
 | C 100nF 0603 |  | C21 | 1 |  |  |  | Digi-Key | 1276-1012-1-ND
 | C 2.2nF 0603 |  | C22 | 1 |  |  |  | Digi-Key | 399-1085-1-ND
 | C 100nF 0603 |  | C23 | 1 |  |  |  | Digi-Key | 1276-1012-1-ND
 | C 10nF 0603 |  | C24 | 1 |  |  |  | Digi-Key | 1276-1009-1-ND
 |  |  | C25 | 1 |  |  |  | Digi-Key | 493-6390-1-ND
 | C 100nF 0603 |  | C26 | 1 |  |  |  | Digi-Key | 1276-1012-1-ND
 | C 100nF 0603 |  | C27 | 1 |  |  |  | Digi-Key | 1276-1012-1-ND
 | C 100nF 0603 |  | C28 | 1 |  |  |  | Digi-Key | 1276-1012-1-ND
 | C 100nF 0603 |  | C29 | 1 |  |  |  | Digi-Key | 1276-1012-1-ND
 | C 4.7uF 0603 |  | C30 | 1 |  |  |  | Digi-Key | 1276-1045-1-ND
 | C 100nF 0603 |  | C31 | 1 |  |  |  | Digi-Key | 1276-1012-1-ND
 | C 1uF 0603 |  | C32 | 1 |  |  |  | Digi-Key | 1276-6617-1-ND
 | C 100nF 0603 |  | C33 | 1 |  |  |  | Digi-Key | 1276-1012-1-ND
 | C 100nF 0603 |  | C34 | 1 |  |  |  | Digi-Key | 1276-1012-1-ND
 | C 100nF 0603 |  | C35 | 1 |  |  |  | Digi-Key | 1276-1012-1-ND
 | C 4.7uF 0603 |  | C36 | 1 |  |  |  | Digi-Key | 1276-1045-1-ND
 | C 100nF 0603 |  | C37 | 1 |  |  |  | Digi-Key | 1276-1012-1-ND
 | C 100nF 0603 |  | C38 | 1 |  |  |  | Digi-Key | 1276-1012-1-ND
 | Schottky 60V/2A |  | D1 | 1 |  |  |  | Digi-Key | NTS260ESFT3GOSCT-ND
 | SMAJ12CA |  | D2 | 1 |  |  |  | Digi-Key | SMAJ12CA-TPMSCT-ND
 | Schottky 60V/2A |  | D3 | 1 |  |  |  | Digi-Key | NTS260ESFT3GOSCT-ND
 | Schottky 60V/2A |  | D4 | 1 |  |  |  | Digi-Key | NTS260ESFT3GOSCT-ND
 | LED GREEN |  | D5 | 1 |  |  |  | Digi-Key | 67-1357-1-ND
 | Buck_5A_17V |  | IC1 | 1 |  |  |  | Digi-Key | 296-48755-1-ND
 | LDO_1A_3V3 | IC NCP1117LP LDO | IC2 | 1 |  |  |  | Digi-Key | NCP1117LPST33T3GOSCT-ND
 | TB6612FNG |  | IC3 | 1 |  |  |  | Arrow Electronics | TB6612FNG,C,8,EL
 | MPU-6050 |  | IC4 | 1
 | STM32F446RE |  | IC5 | 1 |  |  |  | Mouser | 511-STM32F446RET6
 | XT30PW |  | J1 | 1
 | Pinheader_2x3 |  | J2 | 1 |  |  |  | Rs | 8281522P
 | PicoBlade_5_Vertical |  | J3 | 1 |  |  |  | Mouser | 538-53047-0510
 | XT30PW |  | J4 | 1
 | XT30PW |  | J5 | 1
 | PicoBlade_4_Vertical |  | J6 | 1 |  |  |  | Mouser | 538-53047-0410
 | PicoBlade_8_Vertical |  | J7 | 1 |  |  |  | Mouser | 538-53047-0810
 | PicoBlade_3_Vertical |  | J8 | 1 |  |  |  | Mouser | 538-53047-0310
 | PicoBlade_5_Vertical |  | J9 | 1 |  |  |  | Mouser | 538-53047-0510
 | TC2070 |  | J11 | 1
 | 2Pin_Male |  | J12 | 1 |  |  |  | Digi-Key | 732-5315-ND
 | TC2030 |  | J13 | 1
 | Pinheader_2x4 |  | J14 | 1 |  |  |  | Rs | 8281522P
 | TC2050 |  | J? | 1
 | L 4.7uH 13A |  | L1 | 1 |  |  |  | Digi-Key | 118-SRP1040VA-4R7MCT-ND
 | L Ferrit Bead |  | L2 | 1 |  |  |  | Digi-Key | 732-1620-1-ND
 | L Ferrit Bead |  | L3 | 1 |  |  |  | Digi-Key | 732-1620-1-ND
 | SK6812B | Angled | P1 | 1
 | SK6812B | Angled | P2 | 1
 | SK6812B | Angled | P3 | 1
 | SK6812B | Angled | P4 | 1
 | WS2812B |  | P5 | 1
 | WS2812B |  | P6 | 1
 | R 10K 0805 |  | R1 | 1 |  |  |  | Digi-Key | 311-10.0KCRCT-ND
 | R 56K 0805 |  | R2 | 1 |  |  |  | Digi-Key | 311-56.0KCRCT-ND
 | R 47K 0805 |  | R3 | 1 |  |  |  | Digi-Key | A106064CT-ND
 | R 10K 0805 |  | R4 | 1 |  |  |  | Digi-Key | 311-10.0KCRCT-ND
 | R 1K5 0805 |  | R5 | 1 |  |  |  | Digi-Key | RNCP0805FTD1K50CT-ND
 | R 1K5 0805 |  | R6 | 1 |  |  |  | Digi-Key | RNCP0805FTD1K50CT-ND
 | R 1K 0805 |  | R7 | 1 |  |  |  | Digi-Key | 311-1.00KCRCT-ND
 | R 1K 0805 |  | R8 | 1 |  |  |  | Digi-Key | 311-1.00KCRCT-ND
 | R 10K 0805 |  | R9 | 1 |  |  |  | Digi-Key | 311-10.0KCRCT-ND
 | R 220R 0805 |  | R10 | 1 |  |  |  | Digi-Key | A129741CT-ND
 | R 220R 0805 |  | R11 | 1 |  |  |  | Digi-Key | A129741CT-ND
 | R 10K 0805 |  | R12 | 1 |  |  |  | Digi-Key | 311-10.0KCRCT-ND
 | R 10K 0805 |  | R13 | 1 |  |  |  | Digi-Key | 311-10.0KCRCT-ND
 | R 220R 0805 |  | R14 | 1 |  |  |  | Digi-Key | A129741CT-ND
 | Slide Switch |  | S1 | 1 |  |  |  | Digi-Key | CWI333-ND
 | TactileButton |  | S2 | 1 |  |  |  | Digi-Key | 679-2380-1-ND
 | TactileButton |  | S3 | 1 |  |  |  | Digi-Key | 679-2380-1-ND

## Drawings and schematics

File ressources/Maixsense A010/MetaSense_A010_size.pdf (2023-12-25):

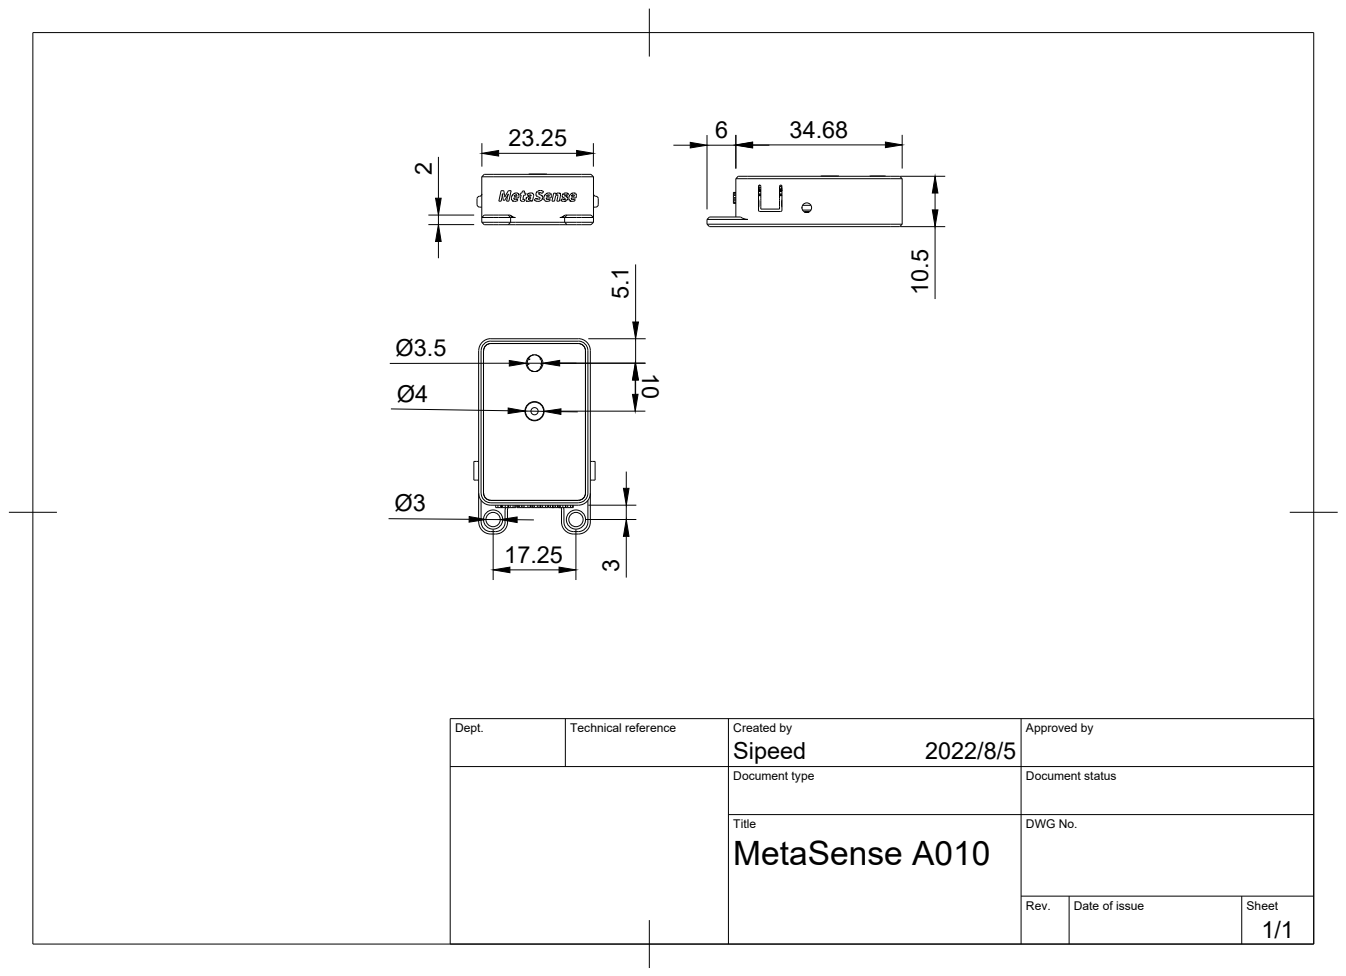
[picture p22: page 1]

Dept. | Technical reference | Created by Sipeed 2022/8/5 | Approved by

Document type | Document status

Title MetaSense A010 | DWG No.

Rev. | Date of issue | Sheet 1/1
